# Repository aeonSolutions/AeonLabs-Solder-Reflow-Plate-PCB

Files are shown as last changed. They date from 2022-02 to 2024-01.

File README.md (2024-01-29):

[PCB-Prototyping-Catalogue](https://github.com/aeonSolutions/PCB-Prototyping-Catalogue)  >>  [DIY & Maker](https://github.com/aeonSolutions/PCB-Prototyping-Catalogue/blob/main/DIY-Maker/README.md)  >> Solder Reflow Plate PCB

<br>


  
 
 

<a href="https://trackgit.com">
trackgit-views
</a>



[](https://www.buymeacoffee.com/migueltomas)




<br />

# Solder Reflow Plate PCB
 Improved Kicad PCB schematics for a DIY Solder Reflow Plate from the original pcb schematic by [AfterEarthLTD](https://github.com/AfterEarthLTD/Solder-Reflow-Plate). AeonLabs Solder Reflow Plate features a Nextion 3.2" LCD Touch and a ESP32 WROOM32 for WiFi and Bluetooth connectivity. 

*Don't forget to LIKE , SHARE and subscribe the free whatsApp group* and if you liked this PCB consider buying me a cup of coffee. Links below.

### Status
  Revision 1.3 needs to cross TX/RX pads or else fails with "no serial data ..."

 revision 2.0 waiting to be tested.

If you have already tested this PCB send me a message.

## Versions
### AeonLabs improved Hot Solder Reflow Plate
- revision 2.x (ToDo)
  - Firmware code for the ESP32 WROOM32 and for the Nextion 3.2" LCD Touch on this Solder Reflow Plate
  - Android App to view and control the hot plate temperature

- revision 2.0
  - Serial TX/RX track lines correction.
  - Added an ON/ OFF switch 
  - Redesigned and new 5.0V and 3.3V power managment for more than 90% efficiency . No more hot LDOs on the PCB! 
 
- revison 1.x
  - Upgraded to ZLDO1117 voltage regulators with copper heat dissipation area
  - ESP32 MCU with BLE and WiFi
  - 2x Temperature seensors for improved management of Reflow temperature
  - 12VDC (5A Minimum)
  - 5.5mm x 2.5mm Barrel Jack
  - With corner M7.5 holes for placement of an aluminium plate on top of the PCB for extended lifetime and durability
  - Electronic components placed on the bottom side for extended lifetime and improved duraility
  - Aluminium plate can now be exported as Gerber to [FlatCAM](http://flatcam.org) and drilled using [Candle](https://github.com/Denvi/Candle) 

<p align="center">
  <a href="https://www.youtube.com/watch?v=1Q-IPH6u9Qg">
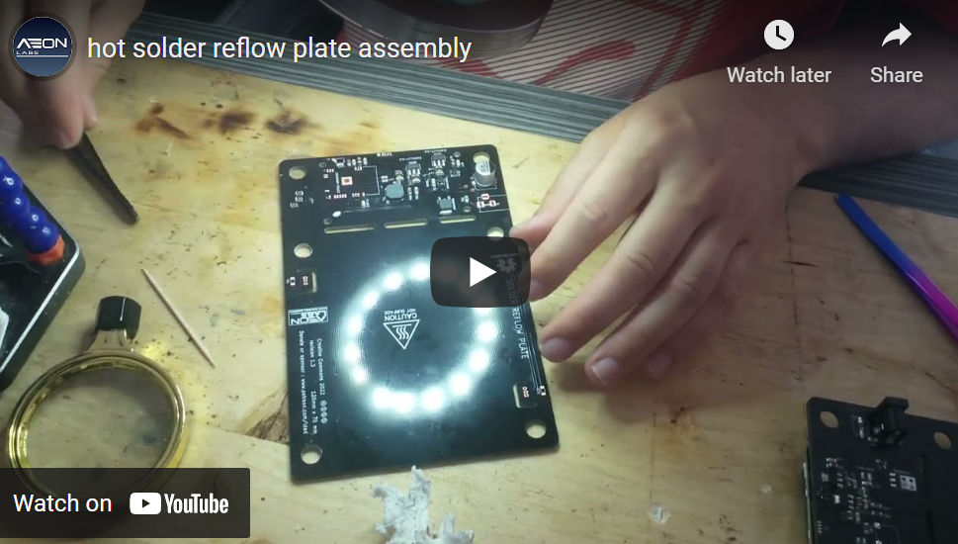
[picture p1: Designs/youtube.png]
   
  </a>
  </p>

### *FlatCAM settings*
 
One can CNC the aluminium base plate on any GBRL CNC machine like this one on AliExpress [here](https://s.click.aliexpress.com/e/_AOOXQ7). Don't forget to use a thin lubricating oil for improved results. 
 
  - Feed Rate: 0.3-0.5 units/min
  - Depth pass: 1.1 mm or 0.04331 inch (unless your setup your CNC with Z-height correction; for a 8mm thick aluminium plate)
  - Tool [CNC Single Flute Milling cutters for Aluminum](https://www.aliexpress.com/item/1005004188243213.html?spm=a2g0o.cart.0.0.3cb23c00L4Ibog&mp=1): 2mm or 0.07874 inch
  - pass overlap: 0.0
  
 ________________________________________________________________________________________________________________

### Regular Hot Solder Reflow Plate as seen on GreatScott
- revision 1.0
  - 120mm x 70mm (Bigger hot plate dimensions)
  - 12VDC (5A Minimum)
  - 5.5mm x 2.5mm Barrel Jack
  - 0.91" OLED Display
  - Atmel Mega 328P MCU (this version includes a crystal for programming)
  - With corner M2.5 holes for placement of an aluminium plate on top of the PCB for extended lifetime and durability.

## As Seen On GreatScott! 
This is the Gerber & KiCad files for the Youtuber GreatScott! video "The Best way to reflow solder? Hot Plate to the rescue! DIY or Buy"
Check it out here - [The Best way to reflow solder? Hot Plate to the rescue! DIY or Buy](https://www.youtube.com/watch?v=QarizoUnRfk)

You have 2 options:

Download this repository for the KiCad Files or, download the Gerber files in the release section of this repository

### alternatively if you do not want to build a PCB by yourself, you can buy here:

<p align="center">
  <a href="https://www.tindie.com/stores/aeonlabs/">
    
  </a>
</p>

The price will be around 30eur plus postage fees.
(I will also deliver the assembled PCB with all the components in place at an aditonal cost).

<p align="center">
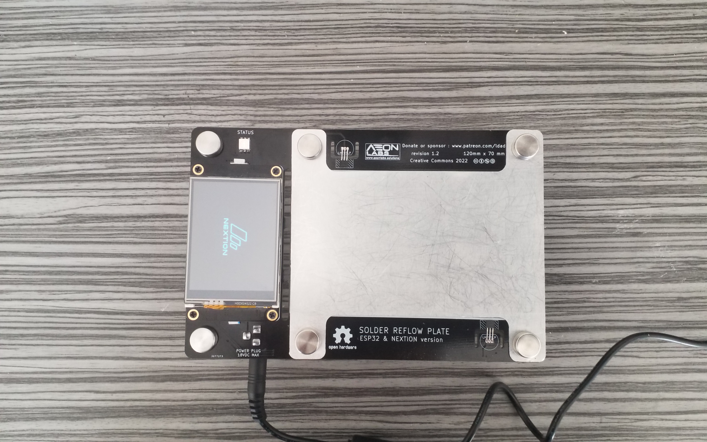
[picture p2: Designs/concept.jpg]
   
</p>
  
<p align="center">
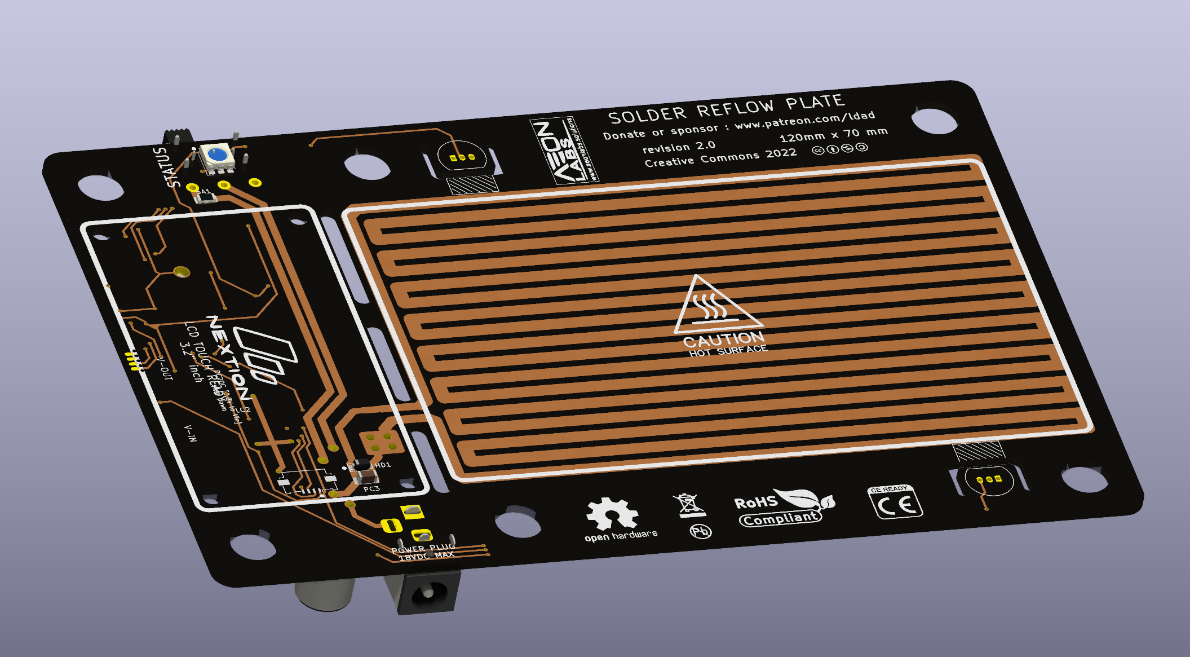
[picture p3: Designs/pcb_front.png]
   
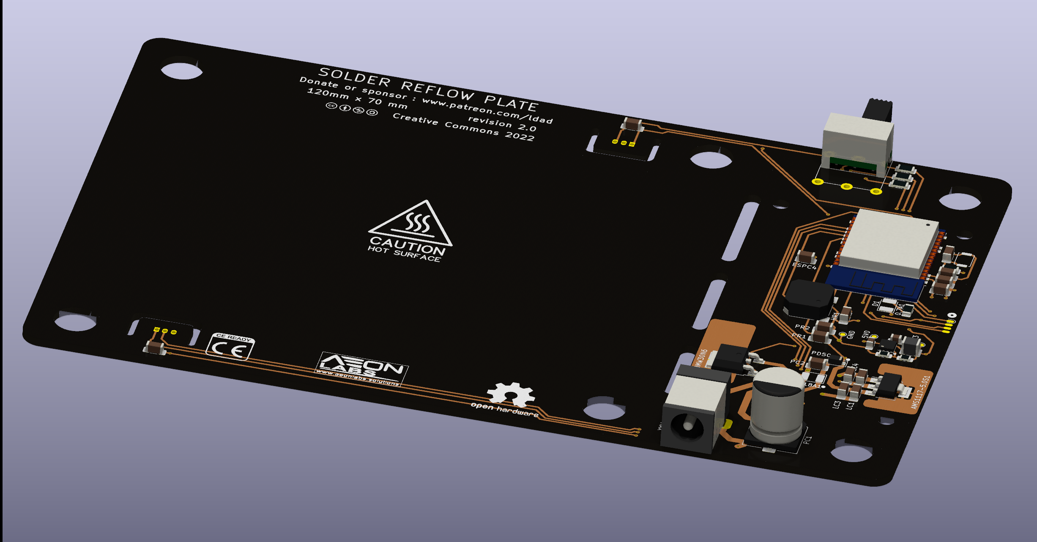
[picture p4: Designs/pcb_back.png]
   
</p>
  
## Liked it ? Get a Free PCB for yourself
Send me your device or hardware and i will design a custom PCB for it. Free of charge. Contact-me on WhatsApp or email for more info. 

|  | *Don't forget to **LIKE** , **SHARE** and **subscribe** the free chat groups* and if you downloaded one of AeonLabs's PCBs consider sponsor  any open hardware project with a donation or a cup of coffee. Links on the top, right side pane and below. |
|---|---|

<br />
<br />

## Q&A WhatsApp/Telegram Groups
|  | Subscribe to the WhatsApp or Telegram channel to get latest information about any of this KiCad projects and get help. Or simply like this kind of projects and want to stay updated with the latest research ideas and prototypes during the day and week.   |
|---|---|

<br />
<br />
<br />

## Youtube Channel
|  | Subscribe to my Youtube channel for PCB assembly instruction or any other related to Artificial Intelligence, Smart devices and robotics. Link to the channel [here](https://www.youtube.com/channel/UCAewCBpMRPGCyFc1ET5CHJw). My most recent video is .... |
|---|---|

#### PCB Parts list:
- 1x AMS1117-3.3, sold on AliExpress [here](https://s.click.aliexpress.com/e/_AOIVLN)
- 1x AMS1117-5.0, sold on AliExpress [here](https://s.click.aliexpress.com/e/_AOIVLN)
- 1x FUSE SMD 1206 5A, sold on AliExpress [here](https://s.click.aliexpress.com/e/_A8yVgJ)
- 1x MM1Z24, sold on AliExpress [here](https://www.aliexpress.com/item/1005003538876461.html?spm=a2g0o.order_list.0.0.2bb91802tqEyK1)
- Barrel Jack, sold on AliExpress [here](https://s.click.aliexpress.com/e/_As3F2L)
- 1x FPC 1x4 pin 1mm pitch horizontal, sold on AliExpress [here](https://s.click.aliexpress.com/e/_ASMTDp)
- 1x FPC flat cable 1mm pitch 4 pin, sold on AliExpress [here](https://s.click.aliexpress.com/e/_9js0C7)
- 1x DSR1M, sold on AliExpress [here](https://s.click.aliexpress.com/e/_9JQobh)
- 1x SMAJ18A, sold on AliExpress [here](https://s.click.aliexpress.com/e/_9zW0DN)
- 2x LMT85LP, sold on AliExpress [here](https://www.aliexpress.com/item/1005003755656556.html?spm=a2g0o.order_list.0.0.42ba1802MVKTRu)
- 1x UMW30N06, sold on AliExpress [here](https://www.aliexpress.com/item/4000687585069.html?spm=a2g0o.order_list.0.0.2bb91802tqEyK1)
- 1x ESP32 WROOM32, sold on AliExpress [here](https://www.aliexpress.com/item/32912371635.html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"sku_id"%3A"65986896288"%7D&pdp_npi=2%40dis%21EUR%21%212.27%21%21%21%21%21%400bb0622916528901078995704e092a%2165986896288%21sea)
- 1x NEXTION 3.2" LCD Touch, sold on AliExpress [here](https://www.aliexpress.com/item/32678581956.html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)

<br />
<br />

## Author

You can get in touch with me on my LinkedIn Profile:

#### Miguel Tomas



<a href="https://stackexchange.com/users/18907312/miguel-silva">profile for Miguel Silva on Stack Exchange, a network of free, community-driven Q&A sites</a>



You can also follow my GitHub Profile to stay updated about my latest projects: 

<br>

**Hire me** <br>
See [here](https://github.com/aeonSolutions/PCB-Prototyping-Catalogue/wiki/How-to-Hire-AeonLabs) how to hire AeonLabs.

<br>

### Be supportive of my dedication and work towards technology education and buy me a cup of coffee
The PCB design Files I provide here for anyone to use are free. If you like this Smart Device or use it, please consider buying me a cup of coffee, a slice of pizza or a book to help me study, eat and think new PCB design files.

<p align="center">
    <a href="https://www.buymeacoffee.com/migueltomas">
        
    </a>
</p>

### Make a donation on PayPal
Make a donation on PayPal and get a TAX refund*.

<p align="center">
    <a href="http://paypal.me/mtpsilva">
        
    </a>
</p>

### Support all these open hardware projects and become a GitHub sponsor  
Liked any of my PCB KiCad Designs? Help and Support my open work to all by becoming a GitHub sponsor.

<p align="center">
    <a href="https://github.com/aeonSolutions/PCB-Prototyping-Catalogue/blob/main/become_a_sponsor/aeonlabs-github-sponsorship-agreement.docx">
        
    </a>
    <a href="https://github.com/sponsors/aeonSolutions">
        
    </a>
</p>

# 

### License

Before proceeding to download any of AeonLabs software solutions for open-source development and/or PCB hardware electronics development make sure you are choosing the right license for your project. See [AeonLabs Solutions for Open Hardware & Source Development](https://github.com/aeonSolutions/PCB-Prototyping-Catalogue/wiki/AeonLabs-Solutions-for-Open-Hardware-&-Source-Development) for more information.

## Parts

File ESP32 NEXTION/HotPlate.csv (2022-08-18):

Source: | F:\Desktop\Arduino IoT devices\PCB Designs\Solder Reflow Plate\ESP32 NEXTION\HotPlate.kicad_sch
Date: | 4/12/2022 12:23
Tool: | Eeschema (6.0.0)
Component Count: | 54
Ref | Value | Footprint | Datasheet | Manufacturer | Vendor
5A1 | Polyfuse | Fuse:Fuse_1206_3216Metric | ~
AMS1117-3.3 | AMS1117-3.3 | Package_TO_SOT_SMD:SOT-223-3_TabPin2 | http://www.advanced-monolithic.com/pdf/ds1117.pdf
AMS1117-5.0 | AMS1117-5.0 | Package_TO_SOT_SMD:SOT-223-3_TabPin2 | http://www.advanced-monolithic.com/pdf/ds1117.pdf
BUZZER1 | Buzzer | Buzzer_Beeper:MagneticBuzzer_Kobitone_254-EMB84Q-RO | ~
D1 | D_Schottky | Diode_SMD:D_1210_3225Metric_Pad1.42x2.65mm_HandSolder | ~
ENR1 | 10k | Resistor_SMD:R_1206_3216Metric | ~
ESP32-WROOM32 | ESP32-WROOM-32 | RF_Module:ESP32-WROOM-32 | https://www.espressif.com/sites/default/files/documentation/esp32-wroom-32_datasheet_en.pdf
ESP_EN_C1 | 0.1uF | Capacitor_SMD:C_1206_3216Metric | ~
ESP_RST_C1 | 0.1uF | Capacitor_SMD:C_1206_3216Metric | ~
ESPC1 | 0.1uF | Capacitor_SMD:C_1206_3216Metric | ~
ESPC2 | 22uF | Capacitor_SMD:C_1206_3216Metric | ~
ESPC4 | 100nF | Capacitor_SMD:C_1206_3216Metric | ~
HD1 | MM1Z24 | Diode_SMD:D_SOD-123 | ~
HR1 | 10K | Capacitor_SMD:C_1206_3216Metric_Pad1.33x1.80mm_HandSolder | ~
J1 | Barrel_Jack_Switch | Connector_BarrelJack:BarrelJack_Horizontal | ~
J2 | Conn_01x08_Male | Connector:SOIC_clipProgSmall | ~
J11 | Conn_01x04_Male | Connector_FFC-FPC:Molex_200528-0040_1x04-1MP_P1.00mm_Horizontal | ~
LC1 | 22uF | Capacitor_SMD:C_1206_3216Metric_Pad1.33x1.80mm_HandSolder | ~
LC2 | 22uF | Capacitor_SMD:C_1206_3216Metric_Pad1.33x1.80mm_HandSolder | ~
LC3 | 100nF | Capacitor_SMD:C_1206_3216Metric_Pad1.33x1.80mm_HandSolder | ~
LC4 | 100nF | Capacitor_SMD:C_1206_3216Metric_Pad1.33x1.80mm_HandSolder | ~
LC5 | 22uF | Capacitor_SMD:C_1206_3216Metric_Pad1.33x1.80mm_HandSolder | ~
LC6 | 22uF | Capacitor_SMD:C_1206_3216Metric_Pad1.33x1.80mm_HandSolder | ~
LC7 | 100nF | Capacitor_SMD:C_1206_3216Metric_Pad1.33x1.80mm_HandSolder | ~
LC8 | 100nF | Capacitor_SMD:C_1206_3216Metric_Pad1.33x1.80mm_HandSolder | ~
LEDR1 | 330R | Resistor_SMD:R_1206_3216Metric | ~
LEDR2 | 330R | Resistor_SMD:R_1206_3216Metric | ~
LEDR3 | 330R | Resistor_SMD:R_1206_3216Metric | ~
PC1 | 100uF | Capacitor_SMD:CP_Elec_6.3x5.9 | ~
PC2 | 100nF | Capacitor_SMD:C_1206_3216Metric_Pad1.33x1.80mm_HandSolder | ~
PC3 | 1nF | Capacitor_SMD:C_1206_3216Metric_Pad1.33x1.80mm_HandSolder | ~
PD1 | DSR1M | Diode_SMD:D_SOD-123F | ~
PR1 | 3K | Capacitor_SMD:C_1206_3216Metric_Pad1.33x1.80mm_HandSolder | ~
PR2 | 1K | Capacitor_SMD:C_1206_3216Metric_Pad1.33x1.80mm_HandSolder | ~
RGBLED1 | LED_RGB | LED_SMD:LED_RGB_5050-6 | ~
RST1 | RST | Button_Switch_SMD:SW_Push_SPST_NO_Alps_SKRK | ~
SMAJ18A1 | SMAJ18A | Diode_SMD:D_1210_3225Metric | https://www.onsemi.com/pub/Collateral/ESD9B-D.PDF
TC1 | 100nF | Capacitor_SMD:C_1206_3216Metric_Pad1.33x1.80mm_HandSolder | ~
U1 | LMT85LP | Sensor:LMT85LP
UMW30N1 | HM | Package_TO_SOT_SMD:TO-252-3_TabPin4 | ~

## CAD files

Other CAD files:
ESP32 NEXTION/CNC plate/hot_plate.dxf

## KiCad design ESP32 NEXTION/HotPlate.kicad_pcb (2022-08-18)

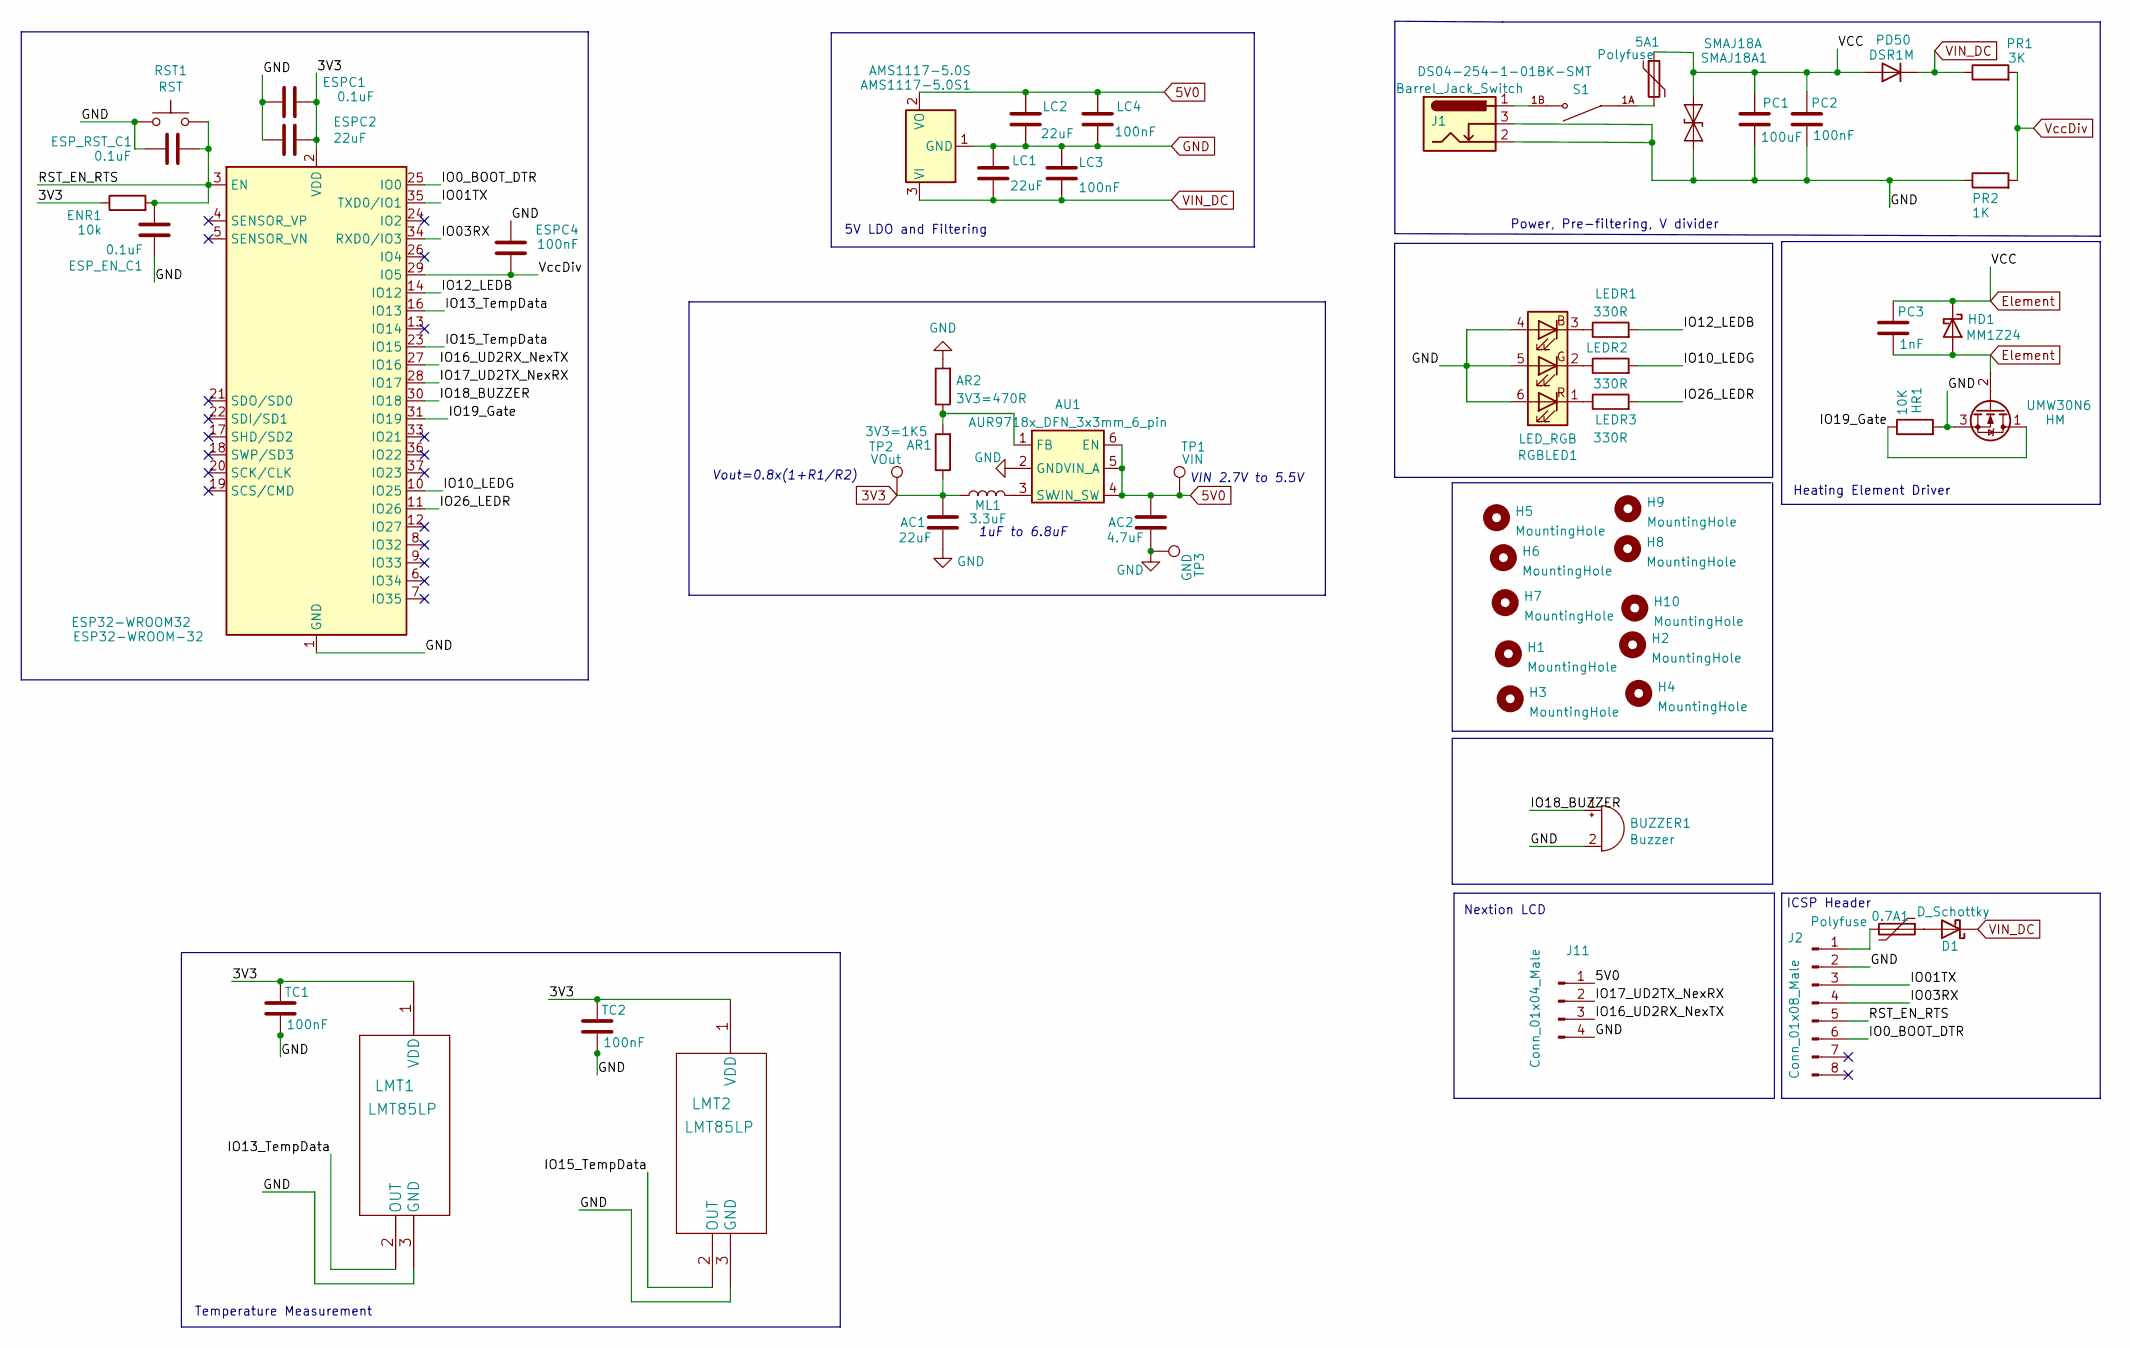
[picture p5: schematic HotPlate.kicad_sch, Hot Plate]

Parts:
0.7A1, 5A1: Polyfuse; Fuse_1206_3216Metric
AC1: 22uF; C_0805_2012Metric_Pad1.18x1.45mm_HandSolder
AC2: 4.7uF; C_0805_2012Metric_Pad1.18x1.45mm_HandSolder
AMS1117-5.0S1: AMS1117-5.0S; SOT-223-3_TabPin2
AR1: 3V3=1K5; R_0805_2012Metric_Pad1.20x1.40mm_HandSolder
AR2: 3V3=470R; R_0805_2012Metric_Pad1.20x1.40mm_HandSolder
AU1: AUR9718x_DFN_3x3mm_6_pin; AUR9718 3x3mm 6 pin
BUZZER1: Buzzer; MagneticBuzzer_Kobitone_254-EMB84Q-RO
D1: D_Schottky; D_1210_3225Metric_Pad1.42x2.65mm_HandSolder
ENR1: 10k; R_1206_3216Metric
ESP32-WROOM32: ESP32-WROOM-32
ESPC1: 0.1uF; C_1206_3216Metric
ESPC2: 22uF; C_1206_3216Metric
ESPC4: 100nF; C_1206_3216Metric
ESP_EN_C1: 0.1uF; C_1206_3216Metric
ESP_RST_C1: 0.1uF; C_1206_3216Metric
H1, H2, H3, H4: MountingHole; MountingHole_3.2mm_M3
H5, H6, H7, H8, H9, H10: MountingHole; MountingHole_8.4mm_M8
HD1: MM1Z24; D_SOD-123
HR1: 10K; C_1206_3216Metric_Pad1.33x1.80mm_HandSolder
J1: Barrel_Jack_Switch; BarrelJack_Horizontal
J2: Conn_01x08_Male; SOIC_clipProgSmall
J11: Conn_01x04_Male; Molex_200528-0040_1x04-1MP_P1.00mm_Horizontal
LC1, LC2: 22uF; C_1206_3216Metric_Pad1.33x1.80mm_HandSolder
LC3, LC4: 100nF; C_1206_3216Metric_Pad1.33x1.80mm_HandSolder
LEDR1, LEDR2, LEDR3: 330R; R_1206_3216Metric
LMT1, LMT2: LMT85LP
ML1: 3.3uF; L_1210_3225Metric
PC1: 100uF; CP_Elec_10x12.5
PC2: 100nF; C_1206_3216Metric_Pad1.33x1.80mm_HandSolder
PC3: 1nF; C_1206_3216Metric_Pad1.33x1.80mm_HandSolder
PD50: DSR1M; D_SOD-123F
PR1: 3K; C_1206_3216Metric_Pad1.33x1.80mm_HandSolder
PR2: 1K; C_1206_3216Metric_Pad1.33x1.80mm_HandSolder
RGBLED1: LED_RGB; LED_RGB_5050-6
RST1: RST; SW_Push_SPST_NO_Alps_SKRK
S1: DS04-254-1-01BK-SMT; Side Switch 3pin 5A; PARTREV V0.0
SMAJ18A1: SMAJ18A; D_1210_3225Metric_Pad1.42x2.65mm_HandSolder
TC1, TC2: 100nF; C_1206_3216Metric_Pad1.33x1.80mm_HandSolder
TP1: VIN; TestPoint_Pad_D1.0mm
TP2: VOut; TestPoint_Pad_D1.0mm
TP3: GND; TestPoint_Pad_D1.0mm
UMW30N6: HM; TO-252-2

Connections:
3V3: AC1.1, AR1.1, ENR1.1, ESP32-WROOM32.2 (VDD), ESPC1.1, ESPC2.1, LMT1.1 (VDD), LMT2.1 (VDD), ML1.1, TC1.1, TC2.1, TP2.1
5V0: AC2.1, AMS1117-5.0S1.2 (VO), AU1.4 (VIN_SW), AU1.5 (VIN_A), AU1.6 (EN), J11.1, LC2.1, LC4.1, TP1.1
/IO0_BOOT_DTR: ESP32-WROOM32.25 (IO0), J2.6
/IO01TX: ESP32-WROOM32.35 (TXD0/IO1), J2.3
/IO03RX: ESP32-WROOM32.34 (RXD0/IO3), J2.4
/IO10_LEDG: ESP32-WROOM32.10 (IO25), LEDR2.2
/IO12_LEDB: ESP32-WROOM32.14 (IO12), LEDR1.2
/IO13_TempData: ESP32-WROOM32.16 (IO13), LMT1.2 (OUT)
/IO15_TempData: ESP32-WROOM32.23 (IO15), LMT2.2 (OUT)
/IO16_UD2RX_NexTX: ESP32-WROOM32.27 (IO16), J11.3
/IO17_UD2TX_NexRX: ESP32-WROOM32.28 (IO17), J11.2
/IO18_BUZZER: BUZZER1.1 (-), ESP32-WROOM32.30 (IO18)
/IO19_Gate: ESP32-WROOM32.31 (IO19), HR1.1, UMW30N6.1 (D)
/IO26_LEDR: ESP32-WROOM32.11 (IO26), LEDR3.2
/RST_EN_RTS: ENR1.2, ESP32-WROOM32.3 (EN), ESP_EN_C1.2, ESP_RST_C1.1, J2.5, RST1.2
Element: 5A1.1, HD1.1 (K), HD1.2 (A), PC1.1, PC2.1, PC3.1, PC3.2, PD50.2 (A), SMAJ18A1.1 (A1), UMW30N6.2 (G)
GND: AC1.2, AC2.2, AMS1117-5.0S1.1 (GND), AR2.2, AU1.2 (GND), BUZZER1.2 (+), ESP32-WROOM32.1 (GND), ESP32-WROOM32.15 (GND), ESP32-WROOM32.38 (GND), ESP32-WROOM32.39 (GND), ESPC1.2, ESPC2.2, ESPC4.2, ESP_EN_C1.1, ESP_RST_C1.2, HR1.2, J1.2, J1.3, J2.2, J11.4, LC1.1, LC2.2, LC3.1, LC4.2, LMT1.3 (GND), LMT2.3 (GND), PC1.2, PC2.2, PR2.1, RGBLED1.4 (BA), RGBLED1.5 (GA), RGBLED1.6 (RA), RST1.1, SMAJ18A1.2 (A2), TC1.2, TC2.2, TP3.1, UMW30N6.3 (S)
unnamed: 0.7A1.1, D1.2 (A)
unnamed: 0.7A1.2, J2.1
unnamed: 5A1.2, S1.1A
unnamed: AR1.2, AR2.1, AU1.1 (FB)
unnamed: AU1.3 (SW), ML1.2
unnamed: J1.1, S1.1B
unnamed: LEDR1.1, RGBLED1.3 (BK)
unnamed: LEDR2.1, RGBLED1.2 (GK)
unnamed: LEDR3.1, RGBLED1.1 (RK)
VIN_DC: AMS1117-5.0S1.3 (VI), D1.1 (K), LC1.2, LC3.2, PD50.1 (K), PR1.1
VccDiv: ESP32-WROOM32.29 (IO5), ESPC4.1, PR1.2, PR2.2

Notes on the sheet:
Power, Pre-filtering, V divider
ICSP Header
Vout=0.8x(1+R1/R2)
Temperature Measurement
Heating Element Driver
1uF to 6.8uF
5V LDO and Filtering
Nextion LCD
VIN 2.7V to 5.5V

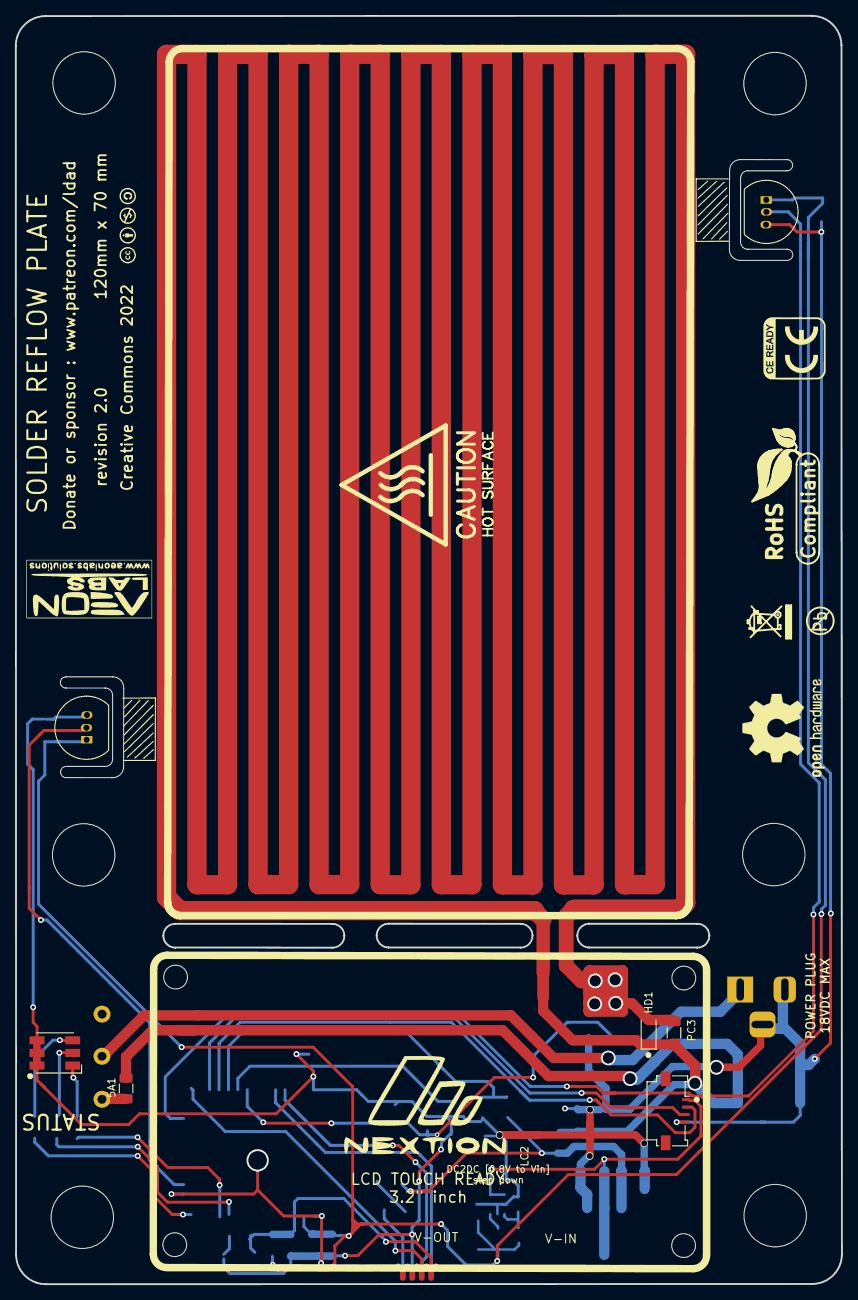
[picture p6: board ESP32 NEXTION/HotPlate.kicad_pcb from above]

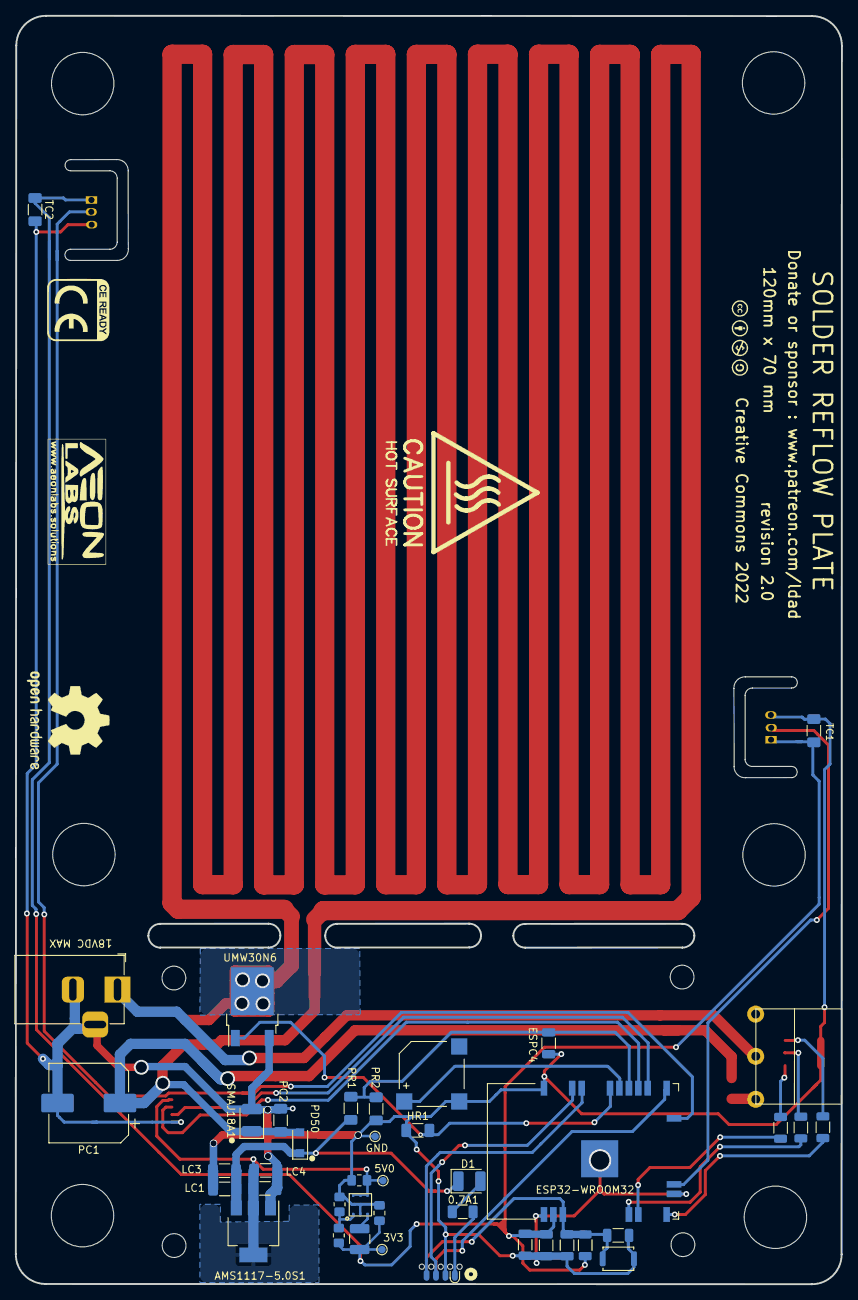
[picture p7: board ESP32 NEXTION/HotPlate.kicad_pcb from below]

Board: 6 copper layers, 111.2 x 170.7 mm, 61 parts (41 on the bottom side), 28 nets.

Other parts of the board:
Sign-PbFree: LOGO_PBFREE
Sign-RecycleBin: LOGO_RECYCLEBIN_1
Sign-RoHS: LOGO_ROHS_1

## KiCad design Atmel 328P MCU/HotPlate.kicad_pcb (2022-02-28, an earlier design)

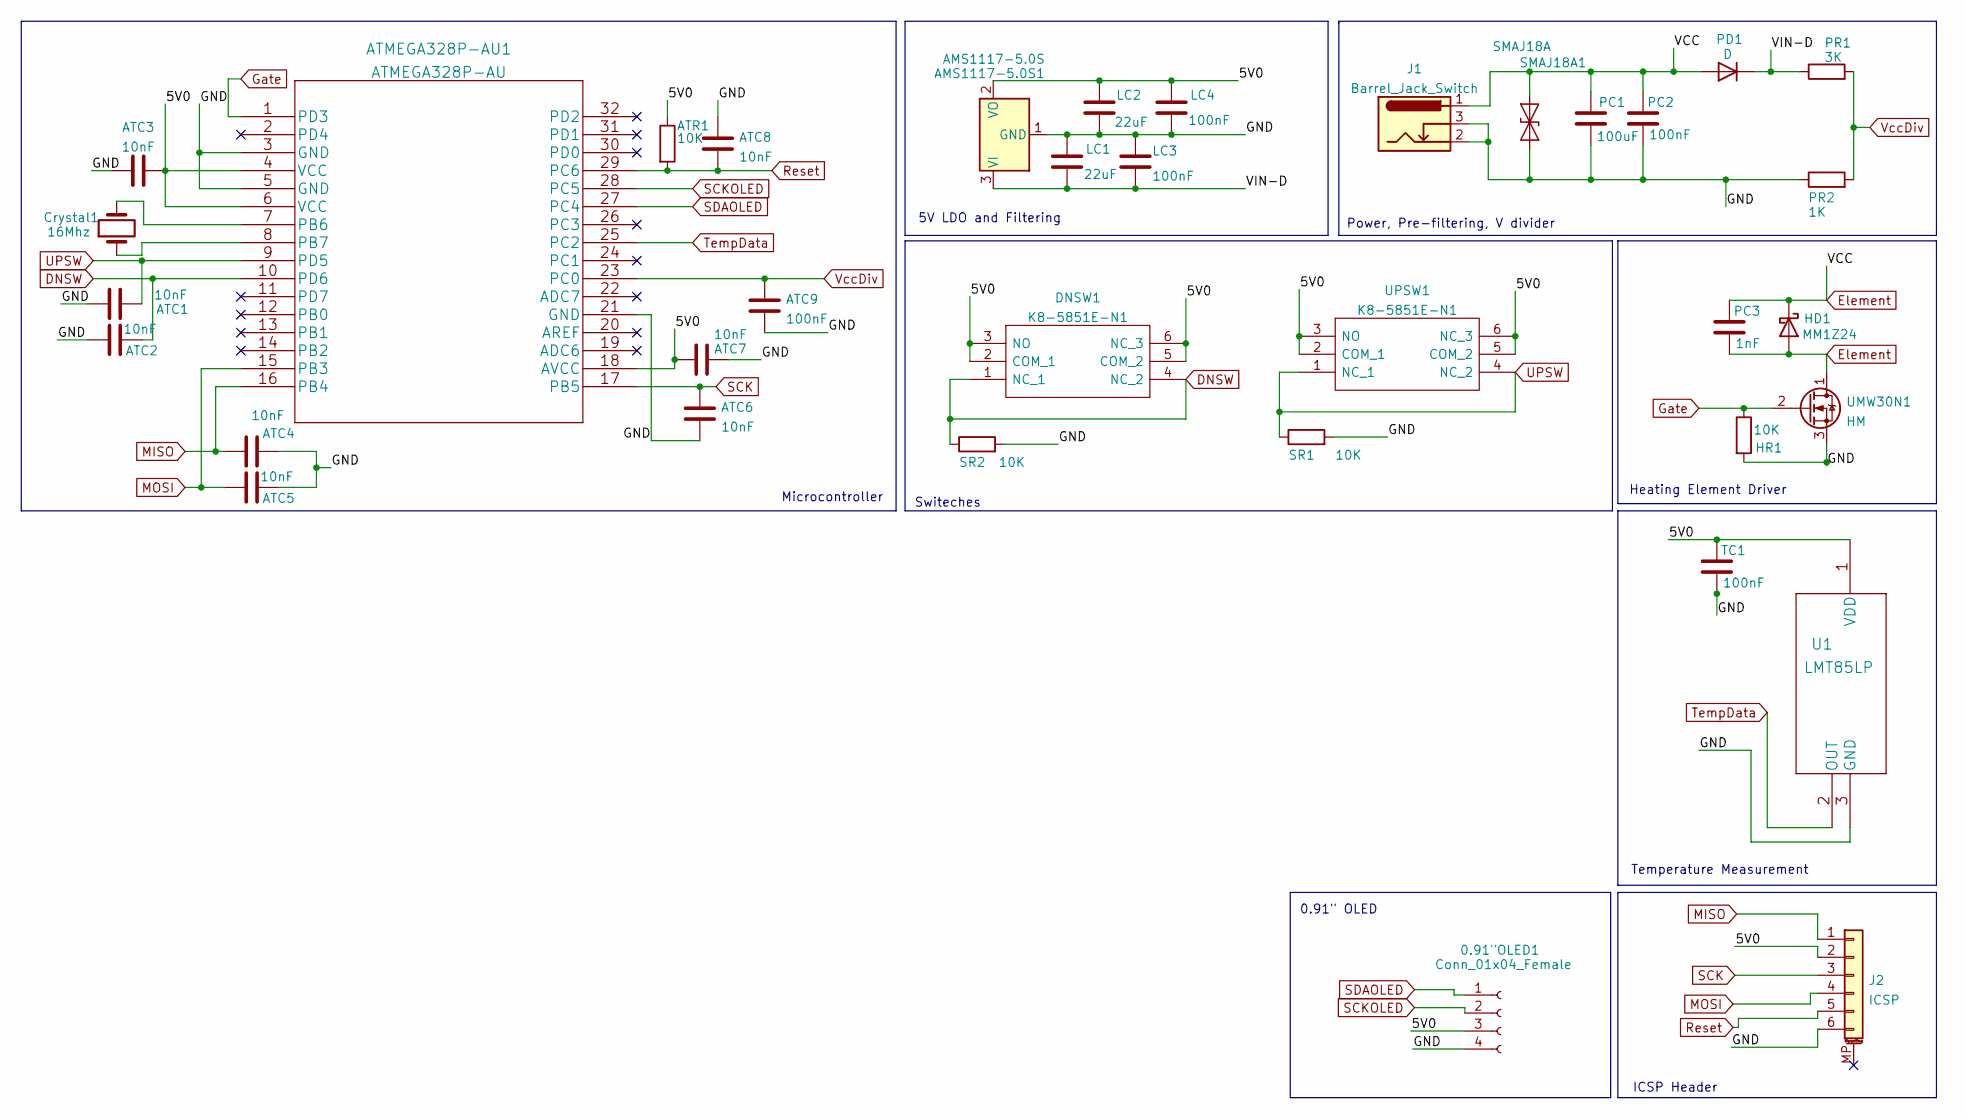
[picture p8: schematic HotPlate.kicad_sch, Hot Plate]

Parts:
0.91"OLED1: Conn_01x04_Female; SSD1306-0.91-OLED-4pin-128x32
AMS1117-5.0S1: AMS1117-5.0S; SOT-223-3_TabPin2
ATC1, ATC2, ATC3, ATC4, ATC5, ATC6, ATC7, ATC8: 10nF; C_1206_3216Metric_Pad1.33x1.80mm_HandSolder
ATC9: 100nF; C_1206_3216Metric_Pad1.33x1.80mm_HandSolder
ATMEGA328P-AU1: ATMEGA328P-AU
ATR1: 10K; R_1206_3216Metric
Crystal1: 16Mhz; Crystal_SMD_5032-2Pin_5.0x3.2mm
DNSW1: K8-5851E-N1; K85851EN1; Manufacturer_Part_Number K8-5851E-N1
HD1: MM1Z24
HR1: 10K; C_1206_3216Metric_Pad1.33x1.80mm_HandSolder
J1: Barrel_Jack_Switch; BarrelJack_Horizontal
J2: ICSP; PinHeader_2x03_P2.54mm_Vertical
LC1, LC2: 22uF; C_1206_3216Metric_Pad1.33x1.80mm_HandSolder
LC3, LC4: 100nF; C_1206_3216Metric_Pad1.33x1.80mm_HandSolder
PC1: 100uF; CP_Elec_6.3x5.9
PC2: 100nF; C_1206_3216Metric_Pad1.33x1.80mm_HandSolder
PC3: 1nF; C_1206_3216Metric_Pad1.33x1.80mm_HandSolder
PD1: D; D_SOD-123
PR1: 3K; C_1206_3216Metric_Pad1.33x1.80mm_HandSolder
PR2: 1K; C_1206_3216Metric_Pad1.33x1.80mm_HandSolder
SMAJ18A1: SMAJ18A; D_SOD-123
SR1, SR2: 10K; C_1206_3216Metric_Pad1.33x1.80mm_HandSolder
TC1: 100nF; C_1206_3216Metric_Pad1.33x1.80mm_HandSolder
U1: LMT85LP
UMW30N1: HM
UPSW1: K8-5851E-N1; K85851EN1; Manufacturer_Part_Number K8-5851E-N1

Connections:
/5V0: 0.91"OLED1.3, AMS1117-5.0S1.2 (VO), ATC3.2, ATC7.1, ATMEGA328P-AU1.4 (VCC), ATMEGA328P-AU1.6 (VCC), ATMEGA328P-AU1.18 (AVCC), ATR1.1, DNSW1.2 (COM_1), DNSW1.3 (NO), DNSW1.5 (COM_2), DNSW1.6 (NC_3), J2.2, LC2.1, LC4.1, TC1.1, U1.1 (VDD), UPSW1.2 (COM_1), UPSW1.3 (NO), UPSW1.5 (COM_2), UPSW1.6 (NC_3)
/GND: 0.91"OLED1.4, AMS1117-5.0S1.1 (GND), ATC1.1, ATC2.1, ATC3.1, ATC4.2, ATC5.2, ATC6.2, ATC7.2, ATC8.1, ATC9.2, ATMEGA328P-AU1.3 (GND), ATMEGA328P-AU1.5 (GND), ATMEGA328P-AU1.21 (GND), HR1.2, J1.2, J1.3, J2.6, LC1.1, LC2.2, LC3.1, LC4.2, PC1.2, PC2.2, PR2.1, SMAJ18A1.1 (A1), SR1.2, SR2.2, TC1.2, U1.3 (GND), UMW30N1.3 (S)
/VIN-D: AMS1117-5.0S1.3 (VI), LC1.2, LC3.2, PD1.1 (K), PR1.1
DNSW: ATC2.2, ATMEGA328P-AU1.10 (PD6), DNSW1.1 (NC_1), DNSW1.4 (NC_2), SR2.1
Element: HD1.1 (K), HD1.2 (A), J1.1, PC1.1, PC2.1, PC3.1, PC3.2, PD1.2 (A), SMAJ18A1.2 (A2), UMW30N1.1 (D)
Gate: ATMEGA328P-AU1.1 (PD3), HR1.1, UMW30N1.2 (G)
MISO: ATC4.1, ATMEGA328P-AU1.16 (PB4), J2.1
MOSI: ATC5.1, ATMEGA328P-AU1.15 (PB3), J2.4
unnamed: ATMEGA328P-AU1.7 (PB6), Crystal1.2
unnamed: ATMEGA328P-AU1.8 (PB7), Crystal1.1
Reset: ATC8.2, ATMEGA328P-AU1.29 (PC6), ATR1.2, J2.5
SCK: ATC6.1, ATMEGA328P-AU1.17 (PB5), J2.3
SCKOLED: 0.91"OLED1.2, ATMEGA328P-AU1.28 (PC5)
SDAOLED: 0.91"OLED1.1, ATMEGA328P-AU1.27 (PC4)
TempData: ATMEGA328P-AU1.25 (PC2), U1.2 (OUT)
UPSW: ATC1.2, ATMEGA328P-AU1.9 (PD5), SR1.1, UPSW1.1 (NC_1), UPSW1.4 (NC_2)
VccDiv: ATC9.1, ATMEGA328P-AU1.23 (PC0), PR1.2, PR2.2

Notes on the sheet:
Power, Pre-filtering, V divider
Microcontroller
ICSP Header
Temperature Measurement
Heating Element Driver
5V LDO and Filtering
0.91" OLED
Switeches

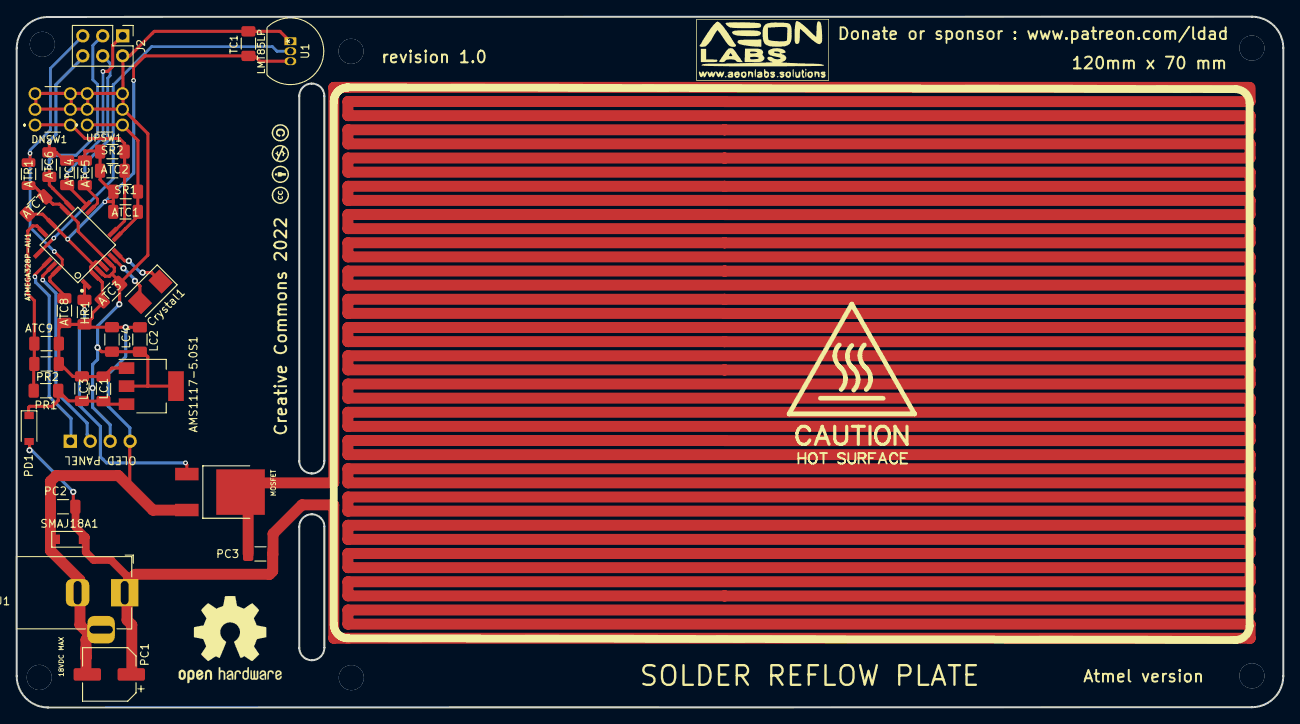
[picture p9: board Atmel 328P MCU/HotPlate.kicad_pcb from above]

Board: 2 copper layers, 161.4 x 88.0 mm, 35 parts (1 on the bottom side), 17 nets.

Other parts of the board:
MOSFET: UMW30N06; TO-252-2_L6.6-W6.1-P4.57-LS9.9-BR-CW

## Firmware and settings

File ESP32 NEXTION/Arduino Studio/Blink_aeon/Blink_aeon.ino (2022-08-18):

#include "pitches.h"
#include "EasyNextionLibrary.h"      // Was modified to accept Serial1 hardware on ESP32
#define nextion Serial2       // This line is for ESP32 with hardware Serial2
//EasyNex  myNextion(nextion);             //create a Nextion object named myNextion using the nextion serial port

// notes in the melody:
int melody[] = {
  NOTE_E5, NOTE_E5, NOTE_E5,
  NOTE_E5, NOTE_E5, NOTE_E5,
  NOTE_E5, NOTE_G5, NOTE_C5, NOTE_D5,
  NOTE_E5,
  NOTE_F5, NOTE_F5, NOTE_F5, NOTE_F5,
  NOTE_F5, NOTE_E5, NOTE_E5, NOTE_E5, NOTE_E5,
  NOTE_E5, NOTE_D5, NOTE_D5, NOTE_E5,
  NOTE_D5, NOTE_G5
};

// note durations: 4 = quarter note, 8 = eighth note, etc, also called tempo:
int noteDurations[] = {
  8, 8, 4,
  8, 8, 4,
  8, 8, 8, 8,
  2,
  8, 8, 8, 8,
  8, 8, 8, 16, 16,
  8, 8, 8, 8,
  4, 4
};

#define BUZZER_PIN 18
#define BUZZER_CHANNEL 0

// setting PWM properties
const int freq = 5000;
const int resolution = 8;

const byte rxPin = 17;
const byte txPin = 16;


 // ********************************************************
 // ********************************************************

void StatusLED(int led, int pauseTime){
    // pausetime in seconds
    digitalWrite(led, HIGH);   // turn the LED on (HIGH is the voltage level)
    delay (pauseTime*1000);
    digitalWrite(led, LOW);   // turn the LED on (HIGH is the voltage level)
    delay (1000);
}

 // ********************************************************
 // ********************************************************
 
void setup(){
  // configure LED PWM functionalitites
  ledcSetup(BUZZER_CHANNEL, freq, resolution);
  // attach the channel to the GPIO to be controlled
  ledcAttachPin(BUZZER_PIN, BUZZER_CHANNEL);

  pinMode(14, OUTPUT);
  pinMode(12, OUTPUT);
  pinMode(27, OUTPUT);
  pinMode(BUZZER_PIN, OUTPUT);


  String sendThis = "page0.t0.txt=\"Thermostat-Heat\"";
  writeString(sendThis);



  Serial.begin(115200);            // USB communication with Serial Monitor
  Serial.print("Starting serial...");

  StatusLED(14, 1);
  
  Serial.print("OK.");
  Serial.println("");
  StatusLED(27, 1);
    
  Serial.print("Starting serial 2...");
  Serial2.begin(9600, SERIAL_8N1, rxPin, txPin);
    
  StatusLED(14, 1);
  
  Serial.print("OK.");
  Serial.println("");
  StatusLED(27, 1);
  
  
  Serial.print("Sending Nextion data...");  
  writeString("BootScreen.sw_rev.txt=\"Software rev.: 0.1\"");
  writeString("BootScreen.hw_rev.txt=\"Hardware rev.: 1.3\"");  
  Serial.print("DONE.");
  Serial.println("");
  
  //myNextion.begin(9600); // Begin the object with a baud rate of 9600 // If no parameter was given in the begin(), the default baud rate of 9600 will be used
  
  //myNextion.sendCommand("rest");   // reset Nextion 
  //myNextion.sendCommand("dim=100");       // Dim to 40% the display

  //myNextion.writeStr("BootScreen.t0.txt", "0.1"); // Set button b0 text to "ON"
  //myNextion.writeStr("BootScreen.hw_rev.txt", "1.3"); // Set button b0 text to "ON"
  
}

 // ********************************************************
 // ********************************************************
void writeString(String stringData)
{
  for (int i = 0; i < stringData.length(); i++)
  {
    // Send one character at a time using Serial2.write, NOT Serial2.print
    Serial2.write(stringData[i]);
  }
  Serial2.write(0xff); // Send three 0xff characters to denote end
  Serial2.write(0xff);
  Serial2.write(0xff);
}

void hideElement(){
  Serial1.print("vis b3,0");
  Serial1.write(0xff);
  Serial1.write(0xff);
  Serial1.write(0xff);  
}
 // ********************************************************
 // ********************************************************
void Tone32(int ch, double note, double duration){
  ledcWriteTone(ch, note);
  delay(duration);
}

void noTone32(){
  ledcWriteTone(BUZZER_CHANNEL, 0);
}
 // ********************************************************
 // ********************************************************


void loop() {
  buzzer();

}
 // ********************************************************
 // ********************************************************

void LED(){
  
  //LED
  digitalWrite(33, HIGH);   // turn the LED on (HIGH is the voltage level)
  delay(1500);                       // wait for a second
  digitalWrite(33, LOW);    // turn the LED off by making the voltage LOW
  delay(1000);                       // wait for a second

  digitalWrite(32, HIGH);   // turn the LED on (HIGH is the voltage level)
  delay(2000);                       // wait for a second
  digitalWrite(32, LOW);    // turn the LED off by making the voltage LOW
  delay(1000);                       // wait for a second

  digitalWrite(27, HIGH);   // turn the LED on (HIGH is the voltage level)
  delay(3000);                       // wait for a second
  digitalWrite(27, LOW);    // turn the LED off by making the voltage LOW
  delay(1000);     
  // wait for a second
}
 // ********************************************************
 // ********************************************************

void buzzer() {
  // iterate over the notes of the melody:
  int size = sizeof(noteDurations) / sizeof(int);

  for (int thisNote = 0; thisNote < size; thisNote++) {
    // to calculate the note duration, take one second divided by the note type.
    //e.g. quarter note = 1000 / 4, eighth note = 1000/8, etc.
    int noteDuration = 1000 / noteDurations[thisNote];
   Tone32(BUZZER_CHANNEL, melody[thisNote], noteDuration);

    // to distinguish the notes, set a minimum time between them.
    // the note's duration + 30% seems to work well:
    int pauseBetweenNotes = noteDuration * 1.30;
    int led = random(1,4);
    if(led==1){
      led=14;
    }
    
    if(led==2){
      led=12;
    }
    
    if(led==3){
      led=27;
    }
    
    digitalWrite(led, HIGH);   // turn the LED on (HIGH is the voltage level)
   
    delay(pauseBetweenNotes);
    // stop the tone playing:
    noTone32();
    digitalWrite(led, LOW);   // turn the LED on (HIGH is the voltage level)
  }
}

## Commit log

2022-04-30 rev. 1.2
    [HotPlate.kicad_pcb, HotPlate.kicad_sch]
2022-04-30 revision 1.2
    [HotPlate.kicad_pcb]
2022-05-18 aluminium base update
    [HotPlate.kicad_pcb]
2022-05-27 revision 1.3
    [HotPlate.kicad_pcb, HotPlate.kicad_sch]
2022-05-31 revision update
    [HotPlate.kicad_pcb, HotPlate.kicad_sch]
2022-06-21 revision update
    Added some HiRes cool phtoos
    [HotPlate.kicad_pcb, HotPlate.kicad_sch]
2022-08-18 rev. 2.0
    added ON/OFF switch
    [HotPlate-B_Adhesive.gbr, HotPlate-B_Courtyard.gbr, HotPlate-B_Cu.gbr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]

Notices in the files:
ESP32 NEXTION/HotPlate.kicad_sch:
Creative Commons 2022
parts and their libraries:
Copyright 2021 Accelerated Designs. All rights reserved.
